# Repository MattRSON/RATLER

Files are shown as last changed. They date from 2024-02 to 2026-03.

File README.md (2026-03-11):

# RATLER
Robotic All Terrain Lunar Exploration Rover

Ratler code base for testing and development

Needs avrgcc from avr8-gnu-toolchain
and make from gnumin32

Flashing on rpi4
scp Microcontroller.hex pi@RATLER:/home/pi/RATLER/AVR/Microcontroller.hex

sudo avrdude -p atmega328p -C /etc/avrdude_gpio.conf -c RATLER -v -U flash:w:MicroController.hex:i

Serial Pinout
1
2 5V
3 MOSI
4 SCK
5 GND
6 MISO
7 3.3V
8 Chip Select
9 Reset

AVR side things to add
- spi communication
    - speed
    - direction
    - position of all wheels
    - flags for onboard sensors
- motor control
    - pwm / speed control
    - direction
    - flags for over temp
- position feedback
    - positional loop so motors know where they are

AVR pcb
- sensor pins ie 3.3v, signal, gnd
    - selectable 5v 3.3v header
- spi and programming header
- led status control
- battery monitor
- sub voltage monitors
- motor control and input header
- motor position header
- analog header
- any unused port has header
- crystal

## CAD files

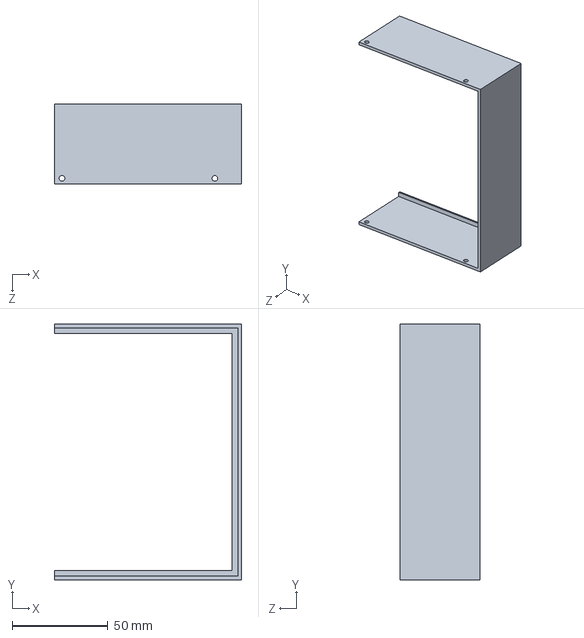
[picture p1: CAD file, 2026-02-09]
3D/holefinder.SLDPRT
98.0 x 134.0 x 42.0 mm

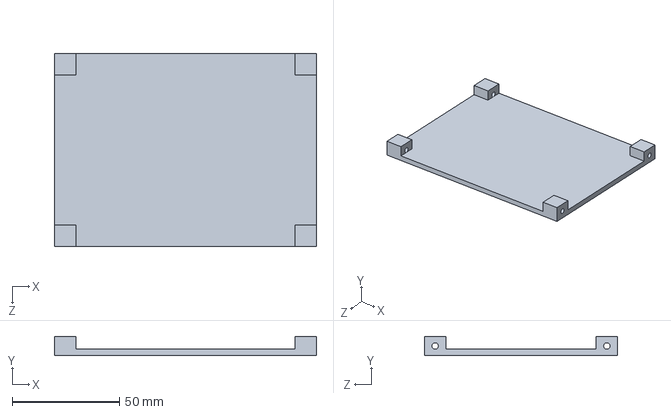
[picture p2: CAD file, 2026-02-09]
Board_RATLER/BlankMount.SLDPRT
122.0 x 9.00 x 90.0 mm

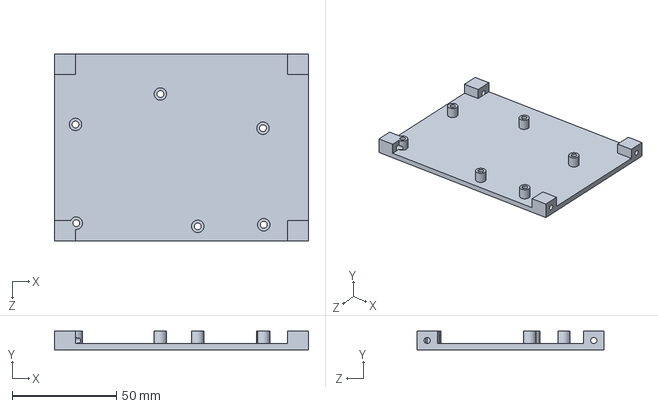
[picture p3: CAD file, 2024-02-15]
3D/PowerboardMount.SLDPRT
122.0 x 9.00 x 90.0 mm

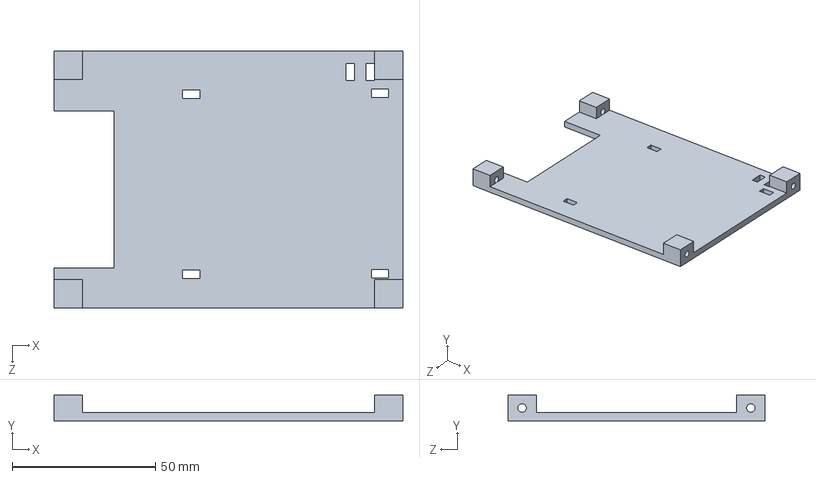
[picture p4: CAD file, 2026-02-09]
Board_RATLER/RpiMount.SLDPRT
122.0 x 9.00 x 90.0 mm

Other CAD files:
3D/MotorDriverMount.SLDPRT
3D/MotorDriverMount.STL
3D/PowerboardMount.STL
3D/holefinder.STL
Board_RATLER/BlankMount.STL
Board_RATLER/RpiMount.STL

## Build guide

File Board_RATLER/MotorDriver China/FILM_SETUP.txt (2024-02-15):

axlFilmCreate( "OUTLINE" ?negative nil ?undefineLineWidth 0.00 ?sequence 3 
	?rotation 0 ?xOffset 0.00 ?yOffset 0.00 ?shapeBoundingBox 100.00 ?mirrored nil ?fullContact nil 
	?suppressUnconnectPads nil ?drawMissingPadApertures nil ?useApertureRotation nil 
	?suppressShapeFill nil ?vectorBasedPad t ?drawHolesOnly nil 
	?domains '(ipc2581 pdf artwork visibility ) ?ipc2581 '() 
	?layers '("BOARD GEOMETRY/DESIGN_OUTLINE" "BOARD GEOMETRY/CUTOUT" ))

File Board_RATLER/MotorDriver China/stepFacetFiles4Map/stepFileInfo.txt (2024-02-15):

#STEP_FILE ! FILE_SIZE ! MOD_TIME

10nfCap.STEP ! 67073 ! 1672692661
470ufCap.STEP ! 47236 ! 1672610549
1ufCap.STEP ! 67314 ! 1671393842
Fuse.STEP ! 115149 ! 1671392978
10mmResistor.STEP ! 126920 ! 1670385747
LMD18200t.STEP ! 350582 ! 1672678373
2x10Pins.STEP ! 523162 ! 1672609927
100nfCap.STEP ! 67076 ! 1671387439
4PinMolex.stp ! 188274 ! 1671391410

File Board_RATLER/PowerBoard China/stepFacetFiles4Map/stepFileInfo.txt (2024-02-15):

#STEP_FILE ! FILE_SIZE ! MOD_TIME

3pinDupont.STEP ! 88303 ! 1671397479
PT6302A.STEP ! 330203 ! 1671390082
1ufCap.STEP ! 67314 ! 1671393842
Fuse.STEP ! 115149 ! 1671392978
PolyFuse.STEP ! 41363 ! 1671395136
Pot.STEP ! 57809 ! 1671397835
100nfCap.STEP ! 67076 ! 1671387439
4PinMolex.stp ! 188274 ! 1671391410
100ufCap.STEP ! 47232 ! 1671384705

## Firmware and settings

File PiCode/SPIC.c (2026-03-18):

// UDP Server listening for drive instructions
#include <stdio.h>      // printf
#include <stdlib.h>     // exit, malloc, free
#include <string.h>     // memset, memcpy, strcmp
#include <unistd.h>     // close, usleep
#include <arpa/inet.h>  // htons, htonl, sockaddr_in, INADDR_ANY
#include <sys/socket.h> // socket, bind, recvfrom
#include <sys/time.h>   // struct timeval, gettimeofday
#include <pigpio.h>     // pigpio library for SPI communication with motor controllers
#include <stdbool.h>   // bool type for flag
#include <time.h>       // time functions for timeout handling


#define PORT 5000 // UDP port
#define PACKET_SIZE 9 // Size of the packet sent from the Steam Deck (x1, y1, x2, y2, L2, R2, dpad_x, dpad_y, buttons)
#define TIMEOUT_MS 200 // Timeout after disconnection (ms)
#define SPI_SPEED 262144 // SPI speed in Hz

int main() {
    // Variables to hold parsed input values initialized to zero
    int8_t x1 = 0; // left stick X
    int8_t y1 = 0; // left stick Y
    int8_t x2 = 0; // right stick X
    int8_t y2 = 0; // right stick Y
    uint8_t L2 = 0; // left trigger
    uint8_t R2 = 0; // right trigger
    int8_t dpad_x = 0; // d-pad X
    int8_t dpad_y = 0; // d-pad Y
    uint8_t buttons = 0; // button bitfield
    bool flag = false; // New data received flag
    bool R1_latch = false; // latch for button bit 4 (prevent repeated action while held)
    bool L1_latch = false; // latch for button bit 5 (prevent repeated action while held)
    int8_t Ldir = 1; // left motor direction multiplier (toggle on button press)
    int8_t Rdir = 1; // right motor direction multiplier (toggle on button press)

    // AVR Struct for spi communication
    typedef struct {
        uint8_t sync;      // 0xAA
        int8_t motor[4]; // Motor speed values (-127 to 127)
        // uint8_t buttons;
        uint8_t checksum;
    } AVRData;

    // Set up UDP socket for receiving packets from the Steam Deck
    int sockfd; // socket descriptor for UDP communication
    struct sockaddr_in server_addr, client_addr; // server/client address info
    socklen_t addr_len = sizeof(client_addr); // size of client address struct
    uint8_t buffer[PACKET_SIZE]; // buffer to hold incoming packet data

    sockfd = socket(AF_INET, SOCK_DGRAM, 0); // create a UDP socket

    server_addr.sin_family = AF_INET; // use IPv4
    server_addr.sin_port = htons(PORT); // set listening port (network byte order)
    server_addr.sin_addr.s_addr = INADDR_ANY; // accept packets on any local interface

    bind(sockfd, (struct sockaddr*)&server_addr, sizeof(server_addr)); // bind socket to the specified port

    printf("UDP Server listening on port %d\n", PORT); // log that server is ready

    // Initialize pigpio library for SPI communication with motor controllers
    if (gpioInitialise()<0) return -1;

    unsigned char DataTX[1];
    unsigned char DataRX[1];

    int handle = spiOpen(0, SPI_SPEED, 0);
    int input;
    printf("SPI Connected to AVR as speed %d\n", SPI_SPEED); // log SPI connection info

    // Variables for timeout handling
    struct timeval last_packet, now; // track the timestamp of the last received packet
    gettimeofday(&last_packet, NULL); // initialize last_packet to current time

    // Main loop to continuously listen for incoming packets and process them
    while (1) {

        // attempt to read a packet without blocking
        int n = recvfrom(sockfd, buffer, PACKET_SIZE, MSG_DONTWAIT,(struct sockaddr*)&client_addr, &addr_len);

        if (n == PACKET_SIZE) { // only process when full packet is received
            gettimeofday(&last_packet, NULL); // update last received time

            x1 = (int8_t)buffer[0]; // left stick X
            y1 = (int8_t)buffer[1]; // left stick Y
            x2 = (int8_t)buffer[2]; // right stick X
            y2 = (int8_t)buffer[3]; // right stick Y
            L2 = buffer[4]; // left trigger
            R2 = buffer[5]; // right trigger
            dpad_x = (int8_t)buffer[6]; // d-pad X
            dpad_y = (int8_t)buffer[7]; // d-pad Y
            buttons = buffer[8]; // button bitfield
            flag = true; // New data received flag

            //printf("X1:%d Y1:%d X2:%d Y2:%d L2:%u R2:%u DPX:%d DPY:%d BTN:%u\n", x1, y1, x2, y2, L2, R2, dpad_x, dpad_y, buttons); // print parsed inputs

        }
        if (flag) {
            // Button press latch: perform the action once on the rising edge of button 4 (bit 4)
            bool R1_pressed = (buttons & (1 << 5)) != 0;
            bool L1_pressed = (buttons & (1 << 4)) != 0;

            if (R1_pressed) {
                if (!R1_latch) {
                    // First packet after the button press: toggle direction multipliers
                    Rdir = -Rdir;
                    R1_latch = true;
                }
            } else {
                // Button released; allow toggle again on next press
                R1_latch = false;
            }

            if (L1_pressed) {
                if (!L1_latch) {
                    // First packet after the button press: toggle direction multipliers
                    Ldir = -Ldir;
                    L1_latch = true;
                }
            } else {
                // Button released; allow toggle again on next press
                L1_latch = false;
            }

            // Always send updated motor command (even while the button is held)
            AVRData DataTX;
                DataTX.sync = 0xAA; // Sync byte to indicate start of packet
                DataTX.motor[0] = Ldir * (L2 / 2); // Mapping: left trigger controls motor 1 speed
                DataTX.motor[1] = Rdir * (R2 / 2); // Mapping: right trigger controls motor 2 speed
                DataTX.motor[2] = Ldir * (L2 / 2); // Mapping: left trigger also controls motor 3 speed
                DataTX.motor[3] = Rdir * (R2 / 2); // Mapping: right trigger also controls motor 4 speed
                // DataTX.buttons = buttons; // Optionally include button states in the packet
                DataTX.checksum = (DataTX.sync + DataTX.motor[0] + DataTX.motor[1] + DataTX.motor[2] + DataTX.motor[3]) & 0xFF; // Simple checksum calculation

            printf("Sending to AVR - Sync: 0x%X, Motors: [%d, %d, %d, %d], Checksum: 0x%X\n", DataTX.sync, DataTX.motor[0], DataTX.motor[1], DataTX.motor[2], DataTX.motor[3], DataTX.checksum); // log the data being sent to AVR
            spiXfer(handle, (unsigned char*)&DataTX, DataRX, sizeof(AVRData)); // Send the structured data over SPI

            flag = false; // reset flag until next packet is received
        }

        gettimeofday(&now, NULL); // get current time for timeout calculation
        long elapsed_ms =
            (now.tv_sec - last_packet.tv_sec) * 1000 + (now.tv_usec - last_packet.tv_usec) / 1000; // ms since last packet

        if (elapsed_ms > TIMEOUT_MS) { // if no packet has arrived within timeout
            // Watchdog: Controller disconnected
                AVRData DataTX;
                    DataTX.sync = 0xAA;
                    DataTX.motor[0] = 0;
                    DataTX.motor[1] = 0;
                    DataTX.motor[2] = 0;
                    DataTX.motor[3] = 0;
                    DataTX.checksum = (DataTX.sync + DataTX.motor[0] + DataTX.motor[1] + DataTX.motor[2] + DataTX.motor[3]) & 0xFF;
            spiXfer(handle, (unsigned char*)&DataTX, DataRX, sizeof(AVRData)); // Send the structured data over SPI
            printf("No packet received for %ld ms, stopping motors\n", elapsed_ms); // log timeout event
        }

        usleep(1000); // sleep 1ms to avoid busy looping
    }

    close(sockfd); // close the socket (unreachable in current infinite loop)
    spiClose(handle);
    gpioTerminate();
    return 0; // indicate successful exit
}

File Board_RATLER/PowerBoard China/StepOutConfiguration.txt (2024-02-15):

EXPORT_UNIT = Millimeter
EXPORT_PROTOCOL = 214
BARE_BOARD_ONLY = YES
HILIGHTED_PKG = NO
ALT_STEP = NO
IGNORE_STEPDEF = NO
MAPPED_PACKAGE = NO
UNMAPPED_PACKAGE = NO
EXTERNAL_COPPER = YES
INNER_COPPER = YES
MECH_PART = NO
MECH_DRILL = YES
PIN_DRILL = YES
VIA_DRILL = YES
ZIP_FILE = NO

SOURCE_ID = allegro_17.4P001

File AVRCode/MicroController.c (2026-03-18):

/*
Spi communication description
Key value pairs each with 8 bits

keys for Rpi to avr
10000000 Keep alive
11000001 Motor1 Forward Speed 0xC1
11001001 Motor1 Reverse Speed 0xC9
11000010 Motor2 Forward Speed 0xC2
11001010 Motor2 Reverse Speed 0xCA
11000011 Motor3 Forward Speed 0xC3
11001011 Motor3 Reverse Speed 0xCB
11000100 Motor4 Forward Speed 0xC4
11001100 Motor4 Reverse Speed 0xCC
10001001 Brake 0x89
10001010 Debug dump 0x8A


keys for avr to Rpi
11111111 Nothing to report 0xFF
11111110 Speed of Motor 1 0xFE
11111101 Speed of Motor 3
11111100 Batt Voltage
11111011 12V rail
11111010 5V rail
11111001 3.3V rail
11111000 Motor Driver Overtemp
11110111 Motor Current 1
11110110 Motor Current 2
11110101 Motor Current 3
11110100 Motor Current 4

Pin mapping Atmega 328p
B0 - Read motor driver overtemp
B1
B2 - Chip select for SPI
B3 - SPI MOSI
B4 - SPI MISO
B5 - SPI SCK
B6
B7
C0 - ADC0 - Battery Voltage
C1 - ADC1 - 12V rail
C2 - ADC2 - 5V rail
C3 - ADC3 - 3.3V rail
C4 - ADC4 - Motor 1 Current
C5 - ADC5 - Motor 2 Current
C6 - Reset
ADC6 - Motor 3 Current
ADC7 - Motor 4 Current
D0
D1
D2
D3 - Motor Brake
D4 - Motor 1 Direction (left)
D5 - Motor 1 PWM (left)
D6 - Motor 2 PWM (right)
D7 - Motor 2 Direction (right)

To start use just the one timer for PWM, Testing other pin PWM outputs on the same timer later




*/
#ifndef F_CPU
#define F_CPU 8000000UL
#endif

#include <avr/io.h>
#include <avr/interrupt.h>
#include <util/delay.h>
#include <string.h> // for memcpy
#include <stdlib.h> // for abs

#define   SET_BIT(Reg, Bit) (Reg |=  (1 << (Bit)))
#define CLEAR_BIT(Reg, Bit) (Reg &= ~(1 << (Bit)))
#define  FLIP_BIT(Reg, Bit) (Reg ^=  (1 << (Bit)))
#define  TEST_BIT(Reg, Bit) ((Reg >> (Bit)) & 1)

#define PACKET_SIZE 6

// volatile uint8_t key = 0;
// volatile uint8_t value = 0;
//volatile uint8_t avrkey = 0;
//volatile uint8_t avrvalue = 0;
//volatile char flag = 0;

volatile uint8_t rx_buffer[PACKET_SIZE];
volatile uint8_t rx_index = 0;

typedef struct {
        uint8_t sync;      // 0xAA
        int8_t motor[4]; // Motor speed values (-127 to 127)
        // uint8_t buttons;
        uint8_t checksum;
    } AVRData;

volatile AVRData packet_active;
volatile AVRData packet_shadow;
volatile uint8_t packet_ready = 0;

void SPI_SlaveInit(void) {
    // Set MISO as output
    SET_BIT(DDRB,PB4);
    // Enable SPI
    SET_BIT(SPCR, SPE);
    // Enable SPI interrupt
    SET_BIT(SPCR,SPIE);

    // Enable Global interrupt
    sei();
    
}

void PWM_Init(void) {
    // Set Timer0 to Fast PWM mode, non-inverting output on OC0A and OC0B
    SET_BIT(DDRD, PD6); // OC0A pin as output motor 2 and 4 PWM
    SET_BIT(DDRD, PD5); // OC0B pin as output motor 1 and 3 PWM

    TCCR0A = (1 << WGM00) | (1 << WGM01) | (1 << COM0A1) | (1 << COM0B1);
    // Set prescaler to 64 and start the timer
    TCCR0B = (1 << CS01) | (1 << CS00);

    OCR0A = 0;
    OCR0B = 0;
}

void set_motor(uint8_t motor, uint8_t speed) {
    // motor: 1-4, dir: 0x00 for forward, 0x20 for reverse, speed: 0-127
    // Speed controlled by PWM, so we can use the speed value to set the duty cycle of the PWM signal for the corresponding motor
    switch (motor)
    {
    case 1:
        // direction control
        if (speed <= 0x00) {
            // Set direction pin for motor 1 to forward
            SET_BIT(PORTD, PD4);
        } else {
            // Set direction pin for motor 1 to reverse
            CLEAR_BIT(PORTD, PD4);
        }

        // speed control
        OCR0B = abs(speed)*2; // Assuming motor 1 is controlled by Timer0 PWM on OC0A (PD6)

        break;
    case 2:
        // direction control
        if (speed <= 0x00) {
            // Set direction pin for motor 2 to forward
            SET_BIT(PORTD, PD7);
        } else {
            // Set direction pin for motor 2 to reverse
            CLEAR_BIT(PORTD, PD7);
        }
        // speed control
        OCR0A = abs(speed)*2; // Assuming motor 2 is controlled by Timer0 PWM on OC0B (PD5)

        break;
    case 3:
        // direction control
        if (speed <= 0x00) {
            // Set direction pin for motor 3 to forward
            SET_BIT(PORTD, PD4); // Example pin, change as needed
        } else {
            // Set direction pin for motor 3 to reverse
            CLEAR_BIT(PORTD, PD4); // Example pin, change as needed
        }
        // speed control
        OCR0B = abs(speed); // Assuming motor 3 is controlled by Timer1 PWM on OC0A (PD6), change as needed

        break;
    case 4:
        // direction control
        if (speed <= 0x00) {
            // Set direction pin for motor 4 to forward
            SET_BIT(PORTD, PD7); // Example pin, change as needed
        } else {
            // Set direction pin for motor 4 to reverse
            CLEAR_BIT(PORTD, PD7); // Example pin, change as needed
        }
        // speed control
        OCR0A = abs(speed)*2; // Assuming motor 4 is controlled by Timer1 PWM on OC0B (PD5), change as needed 

        break;
    default:
        break;
    }

}



int main(void) {
    SPI_SlaveInit();
    PWM_Init();
    SET_BIT(DDRD,PD4); // Motor 1 and 3 direction pin
    SET_BIT(DDRD,PD7); // Motor 2 and 4 direction pin

    while (1) {
        if (packet_ready) {

            cli();  // disable interrupts briefly

            memcpy((void*)&packet_active,(void*)&packet_shadow,sizeof(AVRData));

            packet_ready = 0;

            sei();  // re-enable interrupts

            // Now safe to use packet_active
        }

        // Motor control
        for (uint8_t i = 0; i < 2; i++) {
            set_motor(i+1, packet_active.motor[i]);
        }
    }
}

//SPIE flag for interrupt
ISR(SPI_STC_vect)
{
    uint8_t data = SPDR;

    static uint8_t temp_buffer[PACKET_SIZE];

    if (rx_index == 0) {
        if (data != 0xAA) return;
    }

    temp_buffer[rx_index++] = data;

    if (rx_index >= PACKET_SIZE) {

        // Validate checksum: sum(sync + motors) should equal checksum byte
        uint8_t computed = 0;
        for (uint8_t i = 0; i < PACKET_SIZE - 1; i++) {
            computed += temp_buffer[i];
        }

        if (computed == temp_buffer[PACKET_SIZE - 1]) {
            // Copy into shadow struct only if checksum matches
            memcpy((void*)&packet_shadow, temp_buffer, PACKET_SIZE);
            packet_ready = 1;
        }

        rx_index = 0;
    }

    SPDR = 0x00;
}

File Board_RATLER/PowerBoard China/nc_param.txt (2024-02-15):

INTEGER-PLACES         2
DECIMAL-PLACES         5
X-OFFSET               0.000000
Y-OFFSET               0.000000
FEEDRATE               1
COORDINATES            ABSOLUTE
OUTPUT-UNITS           ENGLISH
TOOL-ORDER             INCREASING
REPEAT-CODES           YES
SUPPRESS-LEAD-ZEROES   NO
SUPPRESS-TRAIL-ZEROES  NO
SUPPRESS-EQUAL         NO
TOOL-SELECT            YES
OPTIMIZE_DRILLING      NO
ENHANCED_EXCELLON      YES
TAPE-FILE              C:/Users/mattr/Documents/GitHub/RATLER/Board_RATLER/PowerBoard China/OutputFiles/PowerBoard.drl
HEADER                 none
LEADER                 12
CODE                   ASCII
SEPARATE               NO
SEPARATE-ROUTING       NO
DRILLING               LAYER-PAIR
BACKDRILL              NO
CAVITY                 NO
COUNTER                NO
TOLERANCE_DRILL        NO
TOLERANCE_TRAVEL       NO
TOOL_SIZE              NO
ROTATION               NO
NON_STANDARD           NO
TOTAL_DRILL            NO
SEPARATE_SLOT          NO
SUPPRESS_TOLERANCE     NO
SUPPRESS_TOOLSIZE      NO
SUPPRESS_ROTATION      NO

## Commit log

2024-02-15 Board File upload
    [CONTROLLER.DSN, MOTORDRIVER.DSN, MotorDriverMount.SLDPRT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]
2024-02-26 interrupt test
2024-02-26 spi test
2024-11-02 button test
2026-02-09 Board Updates
    [BlankMount.SLDPRT, BlankMount.STL, MotorDriverMount.SLDPRT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]
2026-02-11 Back to SPI
2026-02-11 SPI update
2026-02-13 PWM Working
2026-03-11 Update README with flashing instructions for RPi4
    Added instructions for flashing the microcontroller on Raspberry Pi 4.
2026-03-11 Update README with flashing instructions for rpi4
    Added flashing instructions for Raspberry Pi 4.
2026-03-17 spi struct implementation test
2026-03-18 Direction switch
